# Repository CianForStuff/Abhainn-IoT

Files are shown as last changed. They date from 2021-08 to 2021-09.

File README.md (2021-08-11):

# Abhainn-IoT
Abhainn-IoT is a community centered project to provide a base ia platform in withch a network for river monitoring can be establised on 

* Designed for the Sigfox Network - a low power nttweojk designed spificaly for IoT applications 
chech coverage for your area at <a rel="coverage" href="https://www.sigfox.com/en/coverage">Sigfox websight
</a>.
* Incorprates STM32 Lowpower MCU 
* usees a weather sealed Pressure sensor plaqced on the bottom of the PCB to mesure the pressure within the gauge tube, witch then can be converted to a depth 

## To Do 
A few tasks to yet t0 compleet 
* Create suatable enclosure 
* calibeate pressure sensor 
* finilise Device Firmware 

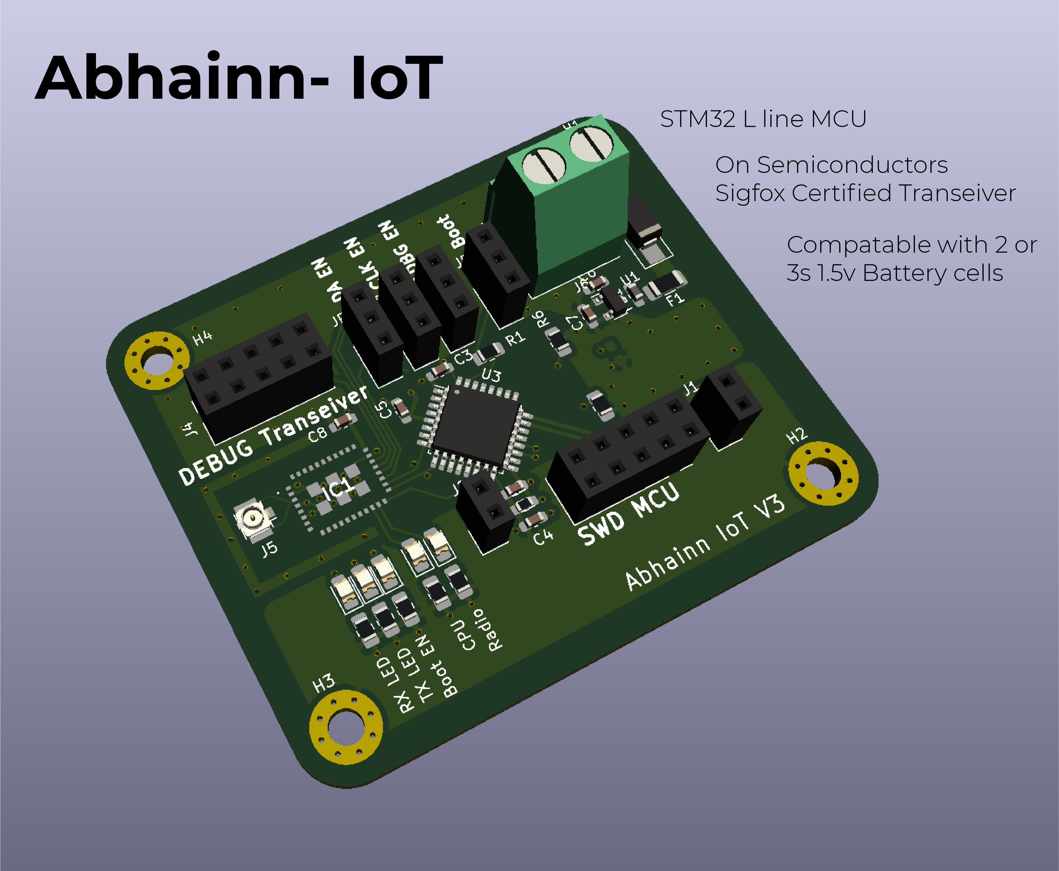
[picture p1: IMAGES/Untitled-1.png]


## Current SCH 
Attached below is the most recent Scheamatic. This is a cureenent ongoing projectso some changes will be made as the validation process contunes
A PDF verson is provide in the IMAGES derectory, and all orher Kicad files are provided 

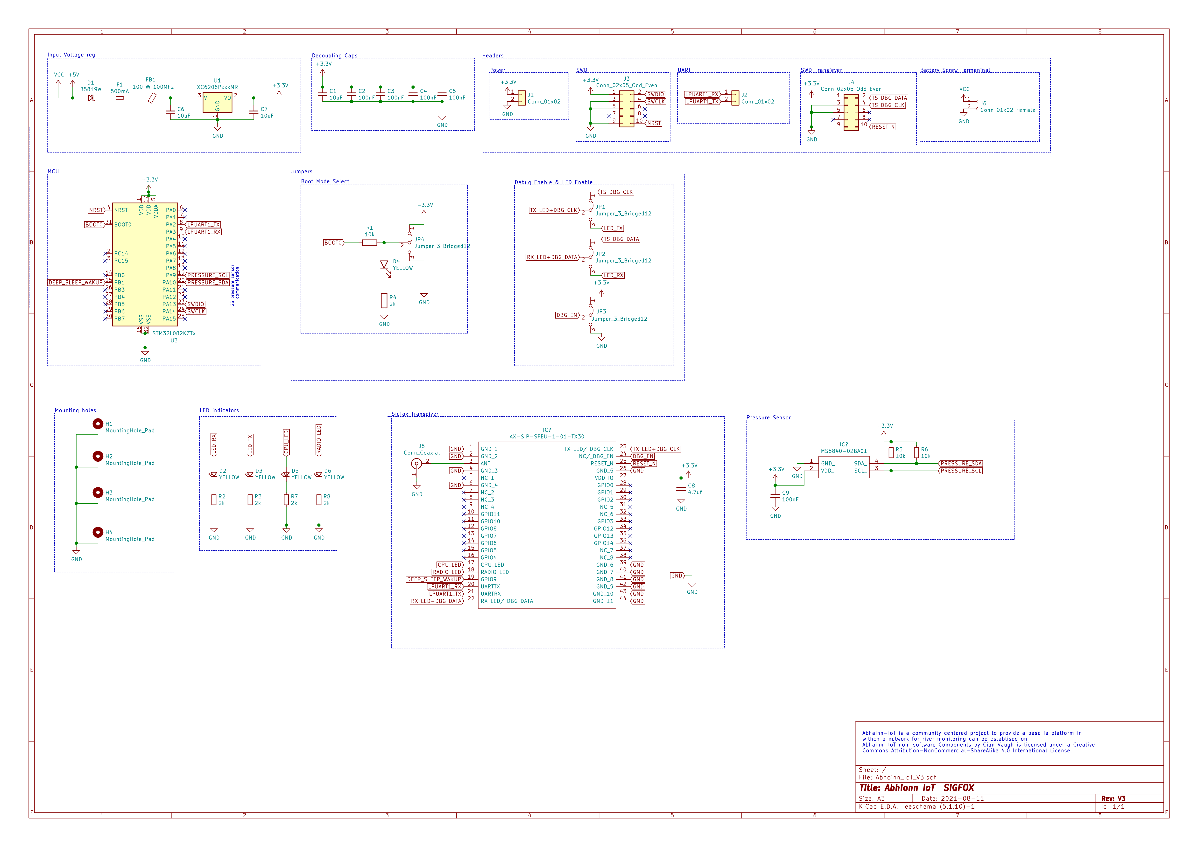
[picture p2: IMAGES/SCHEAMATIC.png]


# licenses 
Software components  is licensed under a <a rel="license" href="https://opensource.org/licenses/LGPL-3.0">GNU Lesser General Public License version 3
</a>.

<br /><span xmlns:dct="http://purl.org/dc/terms/" property="dct:title">Abhainn-IoT non-software Components </span> by <a xmlns:cc="http://creativecommons.org/ns#" href="https://github.com/CianForStuff/Abhainn-IoT" property="cc:attributionName" rel="cc:attributionURL">Cian Vaugh </a> is licensed under a <a rel="license" href="http://creativecommons.org/licenses/by-nc-sa/4.0/">Creative Commons Attribution-NonCommercial-ShareAlike 4.0 International License</a>.

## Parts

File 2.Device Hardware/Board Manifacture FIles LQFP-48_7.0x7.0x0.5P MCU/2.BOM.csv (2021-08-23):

Comment | Designator | Footprint | LCSC
10uF | C1 | Resistor_SMD:R_0603_1608Metric_Pad0.98x0.95mm_HandSolder
10uF | C6,C7 | Capacitor_SMD:C_0603_1608Metric_Pad1.08x0.95mm_HandSolder
4.7uf | C8 | Capacitor_SMD:C_0603_1608Metric_Pad1.08x0.95mm_HandSolder
100nF | C2,C3,C4,C5,C9 | Capacitor_SMD:C_0603_1608Metric_Pad1.08x0.95mm_HandSolder
B5819W | D1 | Diode_SMD:D_SMA_Handsoldering
YELLOW | D2,D3,D4,D5,D6 | LED_SMD:LED_0805_2012Metric_Castellated
500mA | F1 | Fuse:Fuse_1206_3216Metric_Pad1.42x1.75mm_HandSolder
100 @ 100Mhz | FB1 | Inductor_SMD:L_0603_1608Metric_Pad1.05x0.95mm_HandSolder
MountingHole_Pad | H1,H2,H3,H4 | MountingHole:MountingHole_3.2mm_M3_Pad_Via
AX-SIP-SFEU-1-01-TX30 | IC1 | AXSIPSFEU101TX30
MS5840-02BA01 | IC2 | MS584002BA01
Conn_01x02 | J1,J2 | Connector_PinSocket_2.54mm:PinSocket_1x02_P2.54mm_Vertical
Conn_02x05_Odd_Even | J3,J4 | Connector_PinSocket_2.54mm:PinSocket_2x05_P2.54mm_Vertical
Conn_Coaxial | J5 | Connector_Coaxial:U.FL_Hirose_U.FL-R-SMT-1_Vertical
Conn_01x02_Female | J6 | TerminalBlock_Phoenix:TerminalBlock_Phoenix_MKDS-1,5-2_1x02_P5.00mm_Horizontal
Jumper_3_Bridged12 | JP1,JP2,JP3,JP4 | Connector_PinSocket_2.54mm:PinSocket_1x03_P2.54mm_Vertical
10k | R1,R5,R6 | Resistor_SMD:R_0805_2012Metric_Pad1.20x1.40mm_HandSolder
2k | R2,R3,R4,R7,R8 | Resistor_SMD:R_0805_2012Metric_Pad1.20x1.40mm_HandSolder
XC6206PxxxMR | U1 | Package_TO_SOT_SMD:SOT-23
STM32L071RBTx | U3 | Package_QFP:LQFP-32_7x7mm_P0.8mm

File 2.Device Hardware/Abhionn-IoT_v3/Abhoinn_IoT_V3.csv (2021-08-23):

Comment | Designator | Footprint | LCSC Part #
10uF Unpolarized capacitor, small symbol | C1 | R_0603_1608Metric_Pad0.98x0.95mm_HandSolder
100nF Unpolarized capacitor, small symbol | C2,C3,C4,C5,C9 | C_0603_1608Metric_Pad1.08x0.95mm_HandSolder
10uF Unpolarized capacitor, small symbol | C6,C7 | C_0603_1608Metric_Pad1.08x0.95mm_HandSolder
4.7uf Unpolarized capacitor, small symbol | C8 | C_0603_1608Metric_Pad1.08x0.95mm_HandSolder
B5819W Schottky diode, small symbol | D1 | D_SMA_Handsoldering
YELLOW Light emitting diode, small symbol | D2,D3,D4,D5,D6 | LED_0805_2012Metric_Castellated
500mA Fuse, small symbol | F1 | Fuse_1206_3216Metric_Pad1.42x1.75mm_HandSolder
100 @ 100Mhz Ferrite bead, small symbol | FB1 | L_0603_1608Metric_Pad1.05x0.95mm_HandSolder
MountingHole_Pad Mounting Hole with connection | H1,H2,H3,H4 | MountingHole_3.2mm_M3_Pad_Via

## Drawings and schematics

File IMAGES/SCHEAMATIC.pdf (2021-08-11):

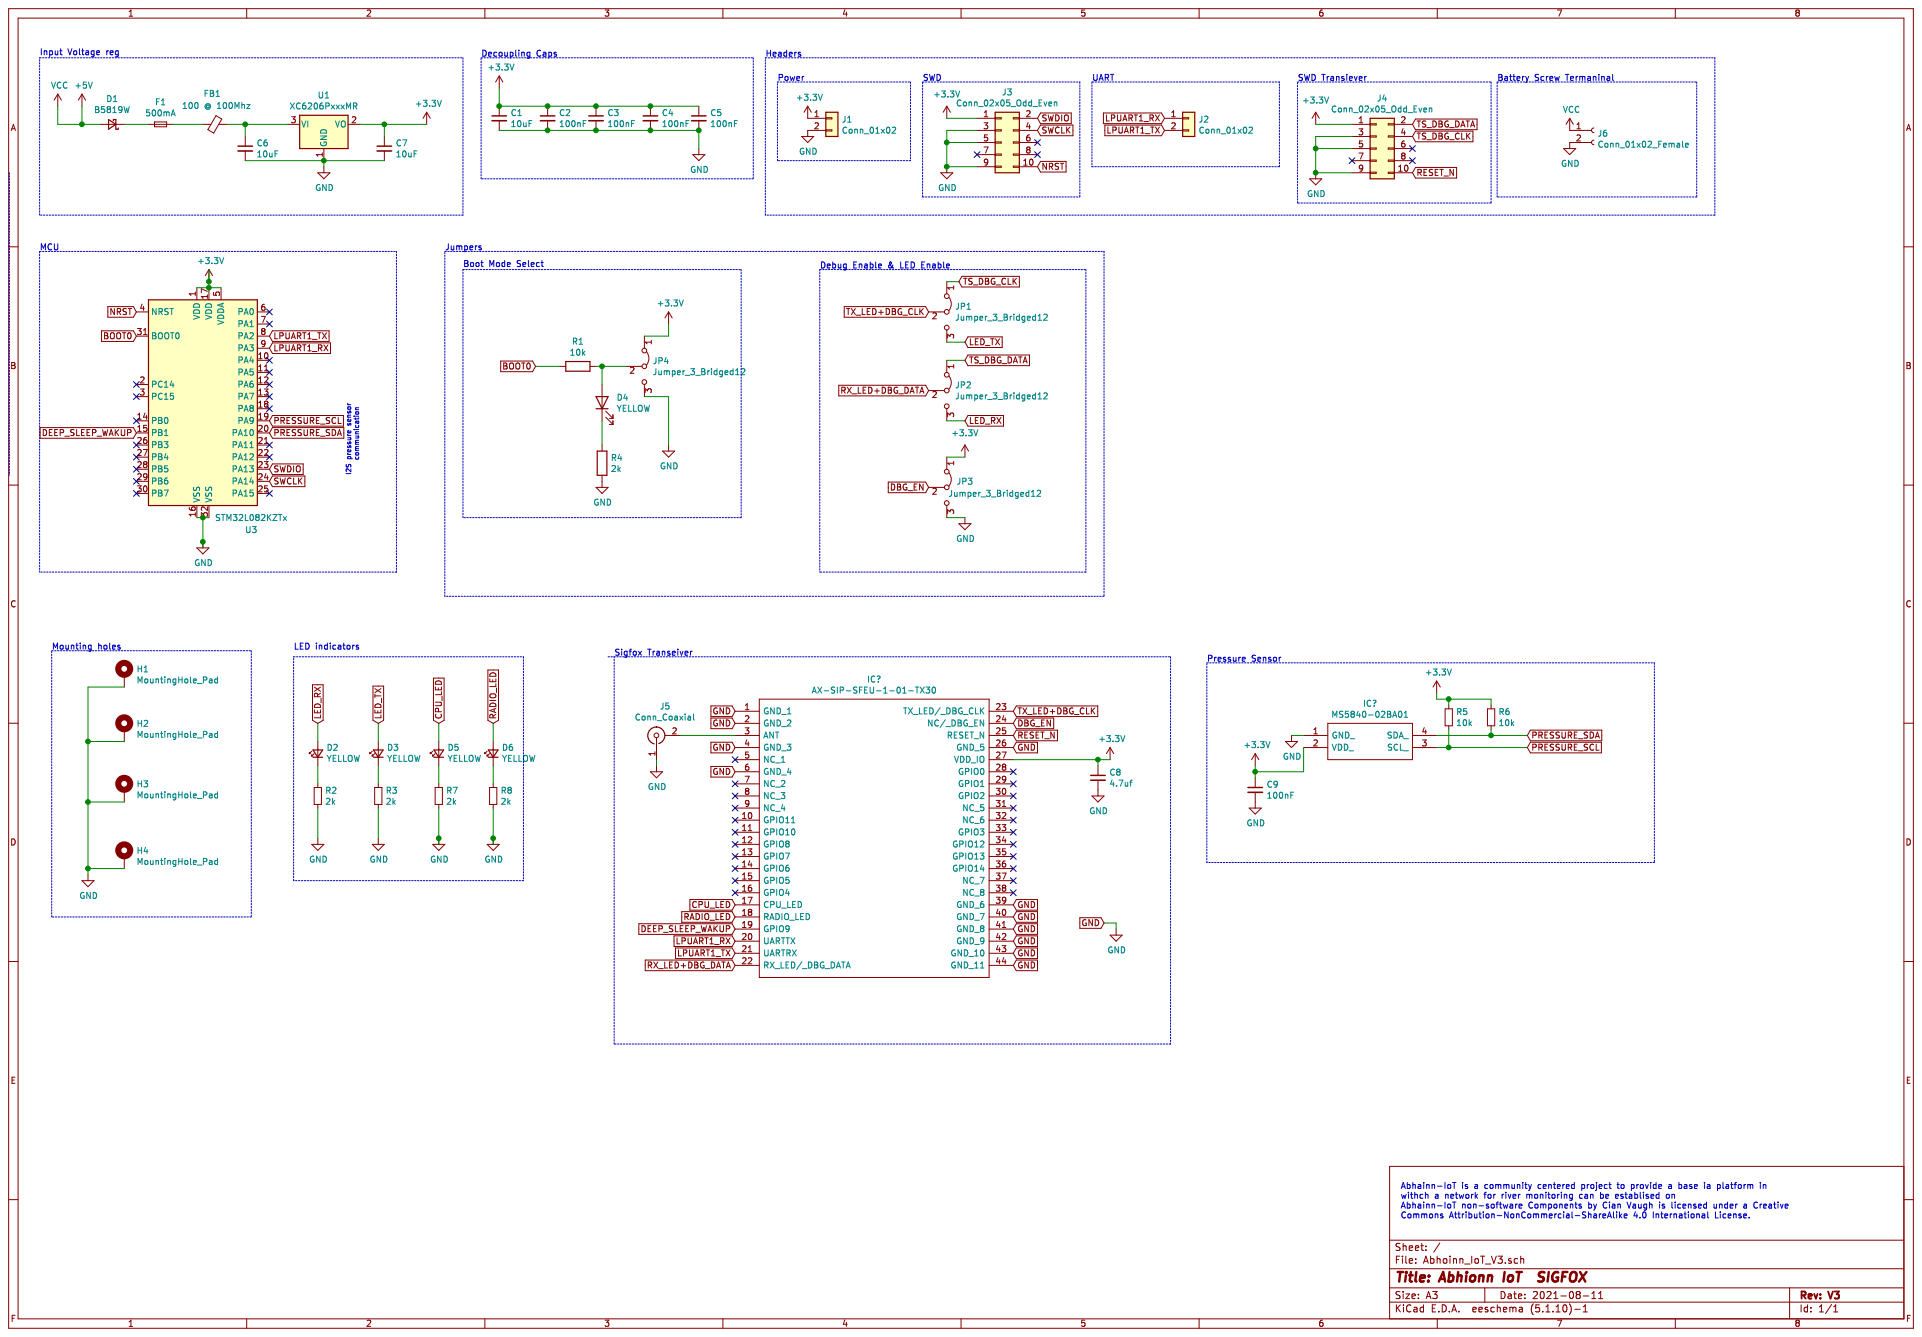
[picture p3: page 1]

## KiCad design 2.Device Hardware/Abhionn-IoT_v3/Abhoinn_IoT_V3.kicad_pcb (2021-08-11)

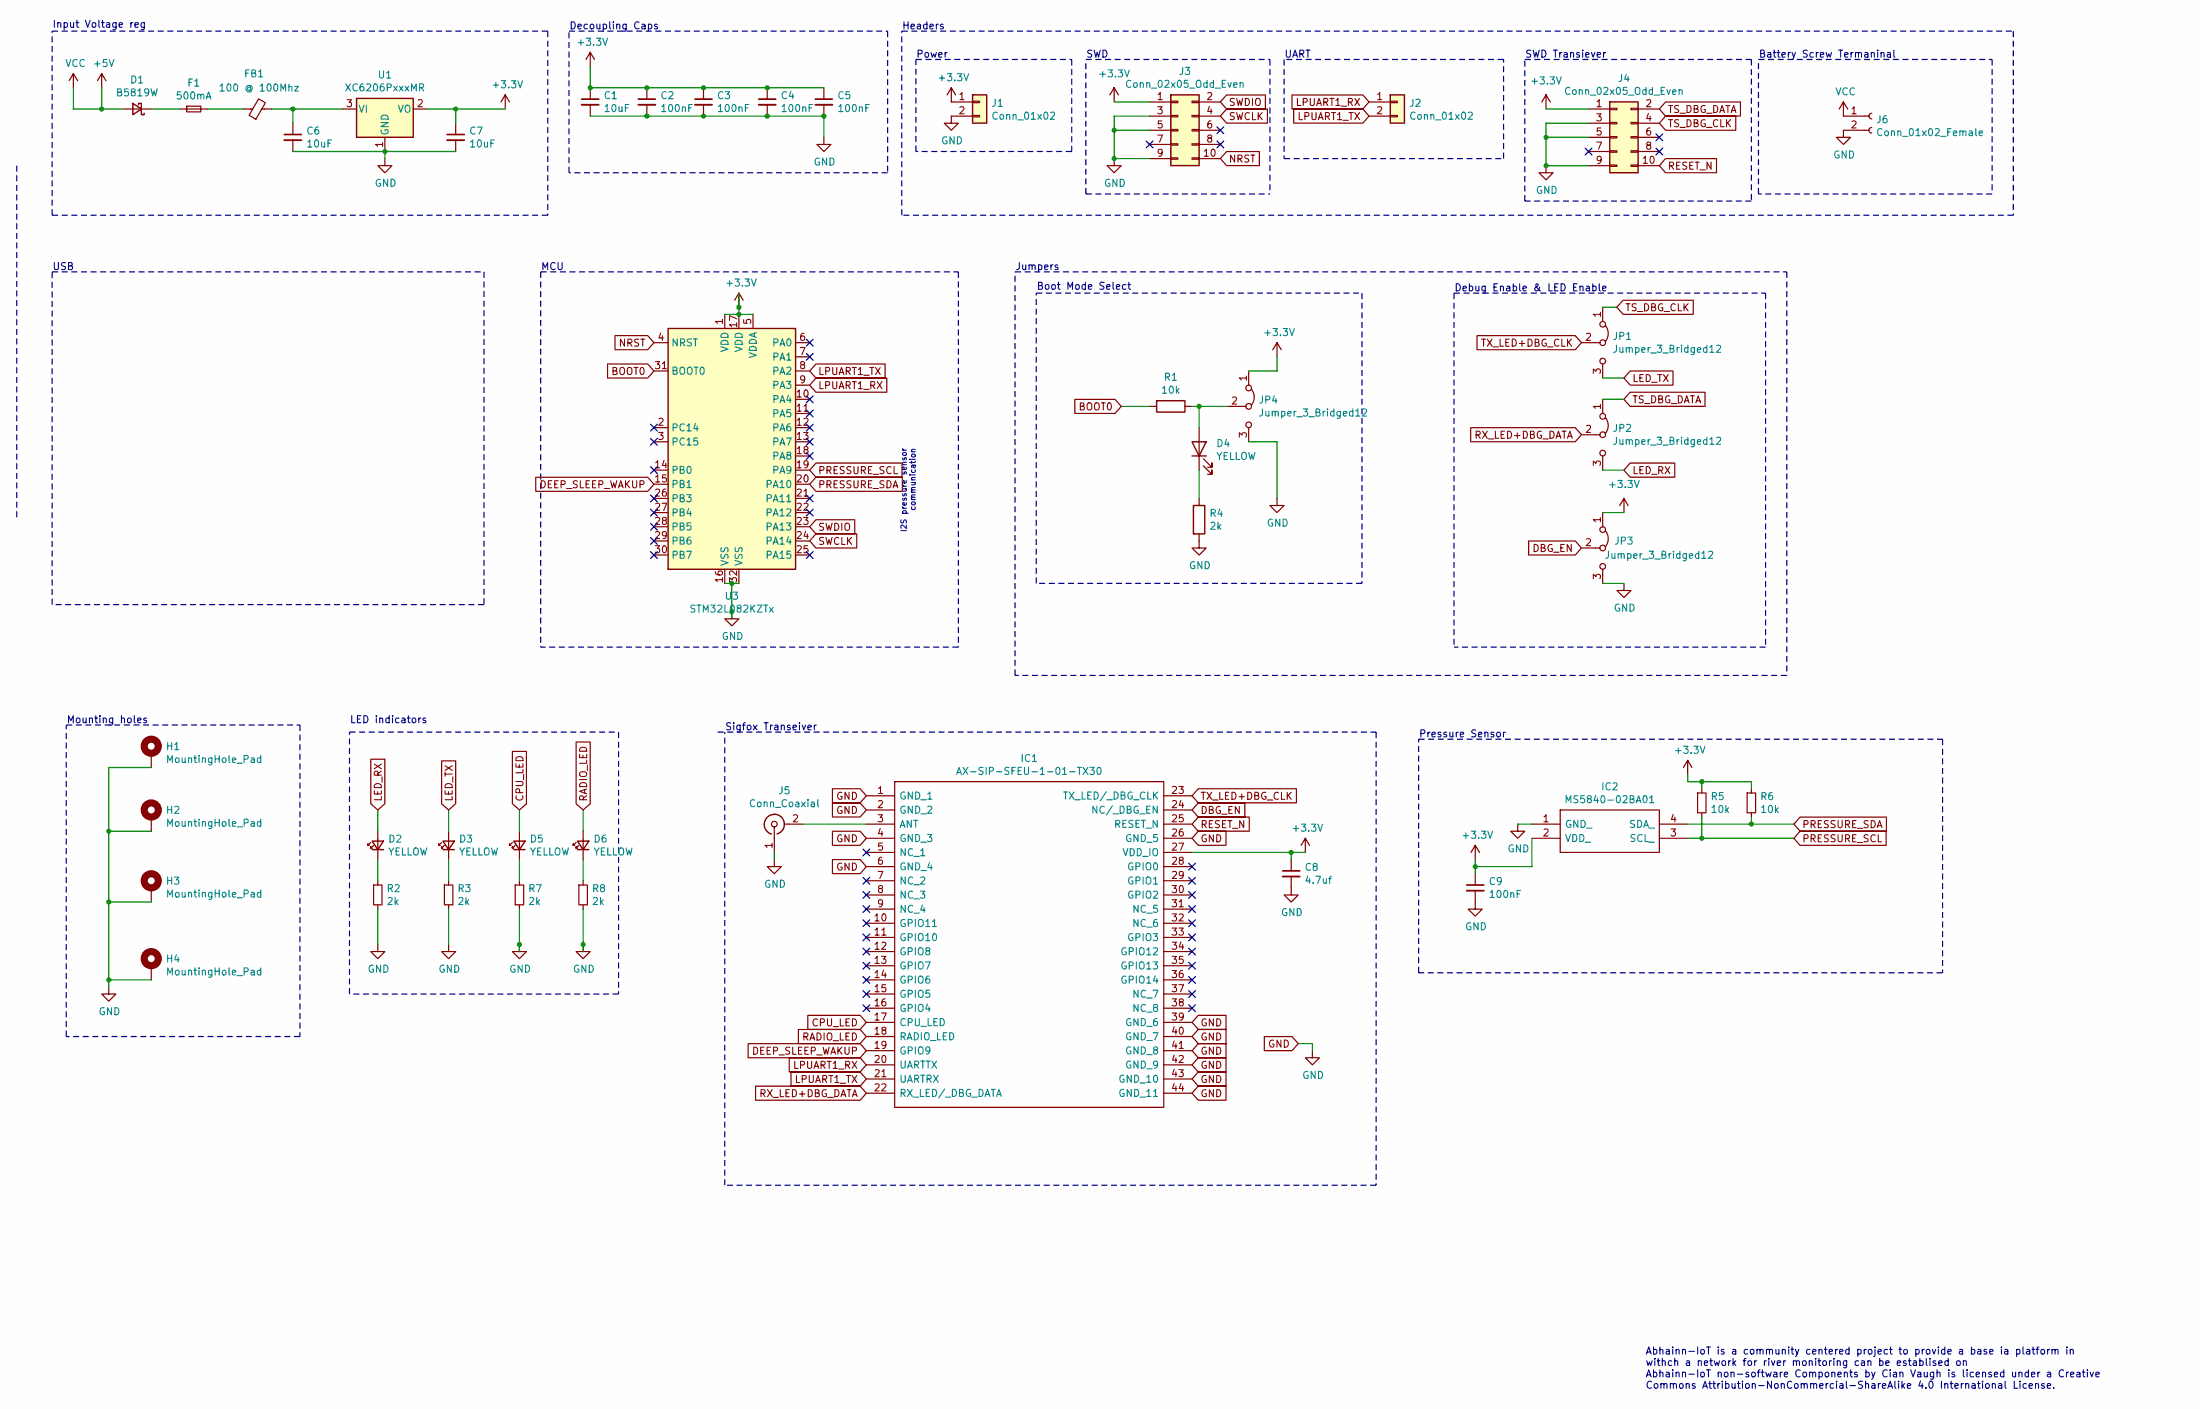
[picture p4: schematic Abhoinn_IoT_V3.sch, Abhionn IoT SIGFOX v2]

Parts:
C1: 10uF; R_0603_1608Metric_Pad0.98x0.95mm_HandSolder; LCSC Part # C19702
C2, C3, C4, C5, C9: 100nF; C_0603_1608Metric_Pad1.08x0.95mm_HandSolder; LCSC Part # C14663
C6, C7: 10uF; C_0603_1608Metric_Pad1.08x0.95mm_HandSolder; LCSC Part # C19702
C8: 4.7uf; C_0603_1608Metric_Pad1.08x0.95mm_HandSolder; LCSC Part # C19666
D1: B5819W; D_SMA_Handsoldering; LCSC Part # C8598
D2, D3, D4, D5, D6: YELLOW; LED_0805_2012Metric_Castellated; LCSC Part # C2296
F1: 500mA; Fuse_1206_3216Metric_Pad1.42x1.75mm_HandSolder
FB1: 100 @ 100Mhz; L_0603_1608Metric_Pad1.05x0.95mm_HandSolder
H1, H2, H3, H4: MountingHole_Pad; MountingHole_3.2mm_M3_Pad_Via
IC1: AX-SIP-SFEU-1-01-TX30; AXSIPSFEU101TX30; Mouser Part Number 863-AXSIPSFEU101TX30
IC2: MS5840-02BA01; MS584002BA01; Mouser Part Number 824-MS5840-02BA01
J1, J2: Conn_01x02; PinSocket_1x02_P2.54mm_Vertical
J3, J4: Conn_02x05_Odd_Even; PinSocket_2x05_P2.54mm_Vertical
J5: Conn_Coaxial; U.FL_Hirose_U.FL-R-SMT-1_Vertical
J6: Conn_01x02_Female; TerminalBlock_Phoenix_MKDS-1,5-2_1x02_P5.00mm_Horizontal
JP1, JP2, JP3, JP4: Jumper_3_Bridged12; PinSocket_1x03_P2.54mm_Vertical
R1, R5, R6: 10k; R_0805_2012Metric_Pad1.20x1.40mm_HandSolder; LCSC Part # C17414
R2, R3, R4, R7, R8: 2k; R_0805_2012Metric_Pad1.20x1.40mm_HandSolder; LCSC Part # C17604
U1: XC6206PxxxMR; SOT-23; LCSC Part # SOT-23-3L
U3: STM32L082KZTx; LQFP-32_7x7mm_P0.8mm

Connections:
+3V3: C1.1, C2.1, C3.1, C4.1, C5.1, C7.1, C8.1, C9.1, IC1.27 (VDD_IO), IC2.2 (VDD_), J1.1, J3.1, J4.1, JP3.1 (A), JP4.1 (A), R5.1, R6.1, U1.2 (VO), U3.1 (VDD), U3.5 (VDDA), U3.17 (VDD)
+5V: D1.2 (A), J6.1
BOOT0: R1.2, U3.31 (BOOT0)
CPU_LED: D5.2 (A), IC1.17 (CPU_LED)
DBG_EN: IC1.24 (NC/_DBG_EN), JP3.2 (C)
DEEP_SLEEP_WAKUP: IC1.19 (GPIO9), U3.15 (PB1)
GND: C1.2, C2.2, C3.2, C4.2, C5.2, C6.2, C7.2, C8.2, C9.2, H1.1, H2.1, H3.1, H4.1, IC1.1 (GND_1), IC1.2 (GND_2), IC1.4 (GND_3), IC1.6 (GND_4), IC1.26 (GND_5), IC1.39 (GND_6), IC1.40 (GND_7), IC1.41 (GND_8), IC1.42 (GND_9), IC1.43 (GND_10), IC1.44 (GND_11), IC2.1 (GND_), J1.2, J3.3, J3.5, J3.9, J4.3, J4.5, J4.9, J5.1 (In), J6.2, JP3.3 (B), JP4.3 (B), R2.2, R3.2, R4.2, R7.2, R8.2, U1.1 (GND), U3.16 (VSS), U3.32 (VSS)
LED_RX: D2.2 (A), JP2.3 (B)
LED_TX: D3.2 (A), JP1.3 (B)
LPUART1_RX: IC1.20 (UARTTX), J2.1, U3.9 (PA3)
LPUART1_TX: IC1.21 (UARTRX), J2.2, U3.8 (PA2)
NRST: J3.10, U3.4 (NRST)
unnamed: C6.1, FB1.2, U1.3 (VI)
unnamed: D1.1 (K), F1.1
unnamed: D2.1 (K), R2.1
unnamed: D3.1 (K), R3.1
unnamed: D4.1 (K), R4.1
unnamed: D4.2 (A), JP4.2 (C), R1.1
unnamed: D5.1 (K), R7.1
unnamed: D6.1 (K), R8.1
unnamed: F1.2, FB1.1
unnamed: IC1.3 (ANT), J5.2 (Ext)
PRESSURE_SCL: IC2.3 (SCL_), R5.2, U3.19 (PA9)
PRESSURE_SDA: IC2.4 (SDA_), R6.2, U3.20 (PA10)
RADIO_LED: D6.2 (A), IC1.18 (RADIO_LED)
RESET_N: IC1.25 (RESET_N), J4.10
RX_LED+DBG_DATA: IC1.22 (RX_LED/_DBG_DATA), JP2.2 (C)
SWCLK: J3.4, U3.24 (PA14)
SWDIO: J3.2, U3.23 (PA13)
TS_DBG_CLK: J4.4, JP1.1 (A)
TS_DBG_DATA: J4.2, JP2.1 (A)
TX_LED+DBG_CLK: IC1.23 (TX_LED/_DBG_CLK), JP1.2 (C)

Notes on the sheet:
Boot Mode Select
Mounting holes
Debug Enable & LED Enable
SWD Transiever
Abhainn-IoT is a community centered project to provide a base ia platform in withch a network for river monitoring can be establised on Abhainn-IoT non-software Components by Cian Vaugh is licensed under a Creative Commons Attribution-NonCommercial-ShareAlike 4.0 International License.
LED indicators
Headers
UART
SWD
Power
Decoupling Caps
Input Voltage reg
MCU
I2S pressure sensor communication
Jumpers
Sigfox Transeiver
Pressure Sensor
Battery Screw Termaninal
USB

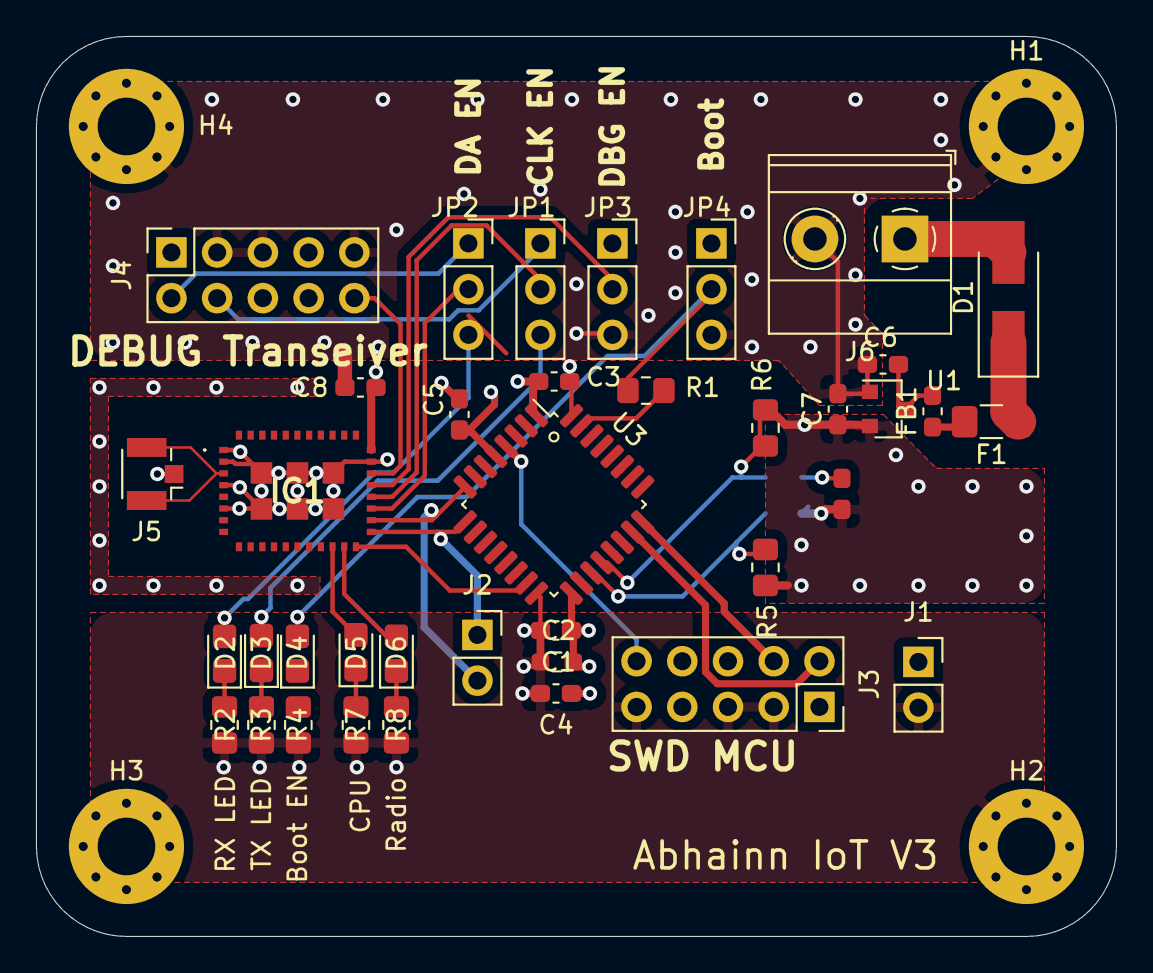
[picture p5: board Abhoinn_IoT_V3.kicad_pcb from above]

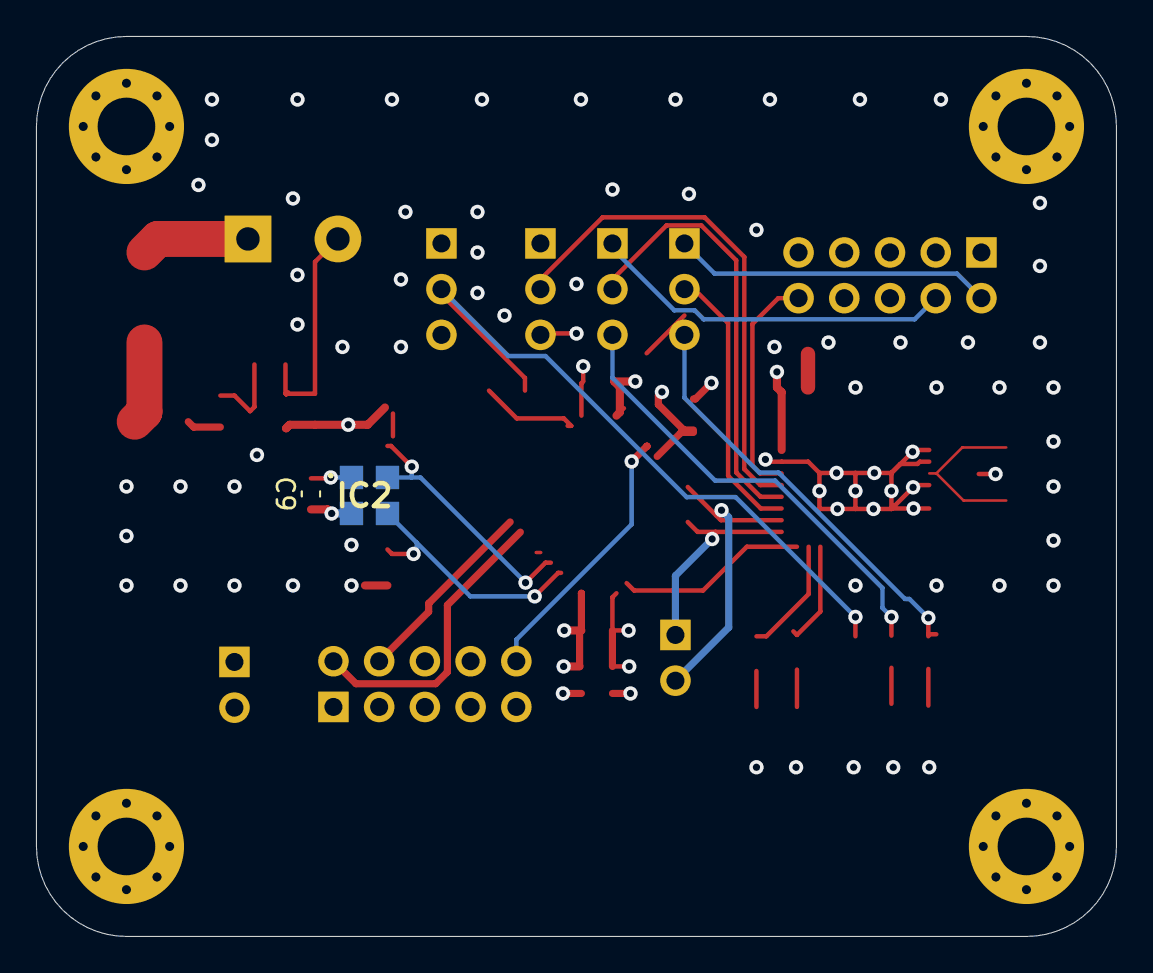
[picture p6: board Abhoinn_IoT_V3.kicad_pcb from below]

Board: 4 copper layers, 60.0 x 50.0 mm, 43 parts (2 on the bottom side), 32 nets.

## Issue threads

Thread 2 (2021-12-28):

Atmospheric presure

seanieb, 2021-12-28:
Cian, love you're taking this on! One thing that was learned from the previous generation of river gauges was the need to cancel out the changes in L/H pressure atmospheric systems. Not sure that will be an issue with this design.

Daithi from Riverspy.net made this guide on IWW, it covers this subject:
https://wiki.iww.ie/index.php/River_Gauges

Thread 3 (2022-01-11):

Suggestion for new pressure sensor

conorf50, 2022-01-11:
Hey Cian!

Class project, i'm excited to see where it goes!

I've a suggestion for the presssure sensor - the TE [SM1391-BCE-S-015-000](https://www.digikey.ie/en/products/detail/SM1391-BCE-S-015-000/223-SM1391-BCE-S-015-000-ND/13913335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)

Comes in a module with tube fittings, and by the looks of it, can be hand soldered (so people without SMD equipment can use it)

[Here's the datasheet](https://www.te.com/commerce/DocumentDelivery/DDEController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)

Cheers,
Conor.

conorf50, 2022-01-17:
Edit: closing this because this sensor is for measuring gas pressure, not water

Closed 2022-01-17.

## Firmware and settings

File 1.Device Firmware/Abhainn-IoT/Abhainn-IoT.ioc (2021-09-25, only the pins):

Mcu.UserName=STM32L031K6Tx
PA9.GPIO_Label=PRESSURE_SCL
PA13.Signal=SYS_SWDIO
PA9.Signal=I2C1_SCL
PA10.GPIO_Label=PRESSURE_SDA
PA2.Signal=LPUART1_TX
PA10.Signal=I2C1_SDA
PA14.Signal=SYS_SWCLK
PA3.Signal=LPUART1_RX

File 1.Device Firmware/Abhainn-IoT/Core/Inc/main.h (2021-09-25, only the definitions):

#define PRESSURE_SCL_Pin GPIO_PIN_9
#define PRESSURE_SCL_GPIO_Port GPIOA
#define PRESSURE_SDA_Pin GPIO_PIN_10
#define PRESSURE_SDA_GPIO_Port GPIOA

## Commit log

2021-06-22 Working Docuemntents
    working documents, not yet complete
    [Gauge MCU+TRANSEIVER_v0.1.kicad_pcb, Gauge MCU+TRANSEIVER_v0.1.sch]
2021-06-28 FIle orginisation
    [Gauge MCU+TRANSEIVER_v0.1.kicad_pcb, Gauge MCU+TRANSEIVER_v0.1.sch]
2021-07-03 initial Clean Up
    [Abhoinn_IoT_V2.kicad_pcb, Abhoinn_IoT_V2.sch, Gauge MCU+TRANSEIVER_v0.1.kicad_pcb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]
2021-07-04 Updated PCB and SCH
    Updated PCB and SCH to add USB interface
    [Abhoinn_IoT_V2.kicad_pcb, Abhoinn_IoT_V2.sch]
2021-07-04 PCB updates
2021-07-04 format SCH, Create PDF
    [Abhoinn_IoT_V2.sch]
2021-07-14 add bom
    [Abhoinn_IoT_V2.csv]
2021-07-16 v2 final and production files
    [Abhoinn_IoT_V2-B_Cu.gbr, Abhoinn_IoT_V2-B_Mask.gbr, Abhoinn_IoT_V2-B_Paste.gbr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]
2021-08-11 Initial Comitte
    [Abhoinn_IoT_V3.kicad_pcb, Abhoinn_IoT_V3.sch]
2021-08-11 Update Drawing
    [Abhoinn_IoT_V3.sch]
2021-08-23 Final Rev layout, Add build Files
    [Abhoinn_IoT_V3-B_Cu.gbr, Abhoinn_IoT_V3-B_Mask.gbr, Abhoinn_IoT_V3-B_Paste.gbr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]
2021-08-23 Update Dir Layout
    [Abhoinn_IoT_V3-B_Cu.gbr, Abhoinn_IoT_V3-B_Mask.gbr, Abhoinn_IoT_V3-B_Paste.gbr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]
2021-09-16 Add layout for 48 pin MCU
    [2.BOM.csv, Abhoinn_IoT_V3.sch, Abhoinn_IoT_V3_48_pin_MCU.kicad_pcb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]

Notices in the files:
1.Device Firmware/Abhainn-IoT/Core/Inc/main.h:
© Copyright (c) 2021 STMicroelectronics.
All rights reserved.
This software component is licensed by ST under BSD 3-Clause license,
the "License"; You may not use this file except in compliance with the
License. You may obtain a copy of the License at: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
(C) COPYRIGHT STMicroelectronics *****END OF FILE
